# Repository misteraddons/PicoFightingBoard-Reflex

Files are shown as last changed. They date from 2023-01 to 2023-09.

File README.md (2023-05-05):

# Reflex Fighting Board

Open source PCB for arcade sticks using Raspberry Pi Pico's RP2040 microcontroller.

## Introduction

They say imitation is the highest form of flattery. If that's the case then the Brook line of arcade controller boards must be blushing beet red. The Reflex Fighting Board uses the same form factor and layout of the Brook PCBs to maintain compatibility with existing arcade stick cases, wiring harnesses, wire management accessories, etc.

The files for PCB production are in the [Releases](https://github.com/misteraddons/ReflexFightingBoard/tree/main/boards/Reflex_V1) section. The zip file contains the Gerber and drill files, which is all you'll need if you're soldering SMT components yourself. There are also `csv` files for the BOM (Bill of Materials) and component positioning for SMT assembly service.

I will also have premade boards periodically available for purchase at <https://misteraddons.com/collections/parts/products/reflex-encode-fighting-board>.

## Versions, Errata & Changelog

Reflex Encode V1.0:

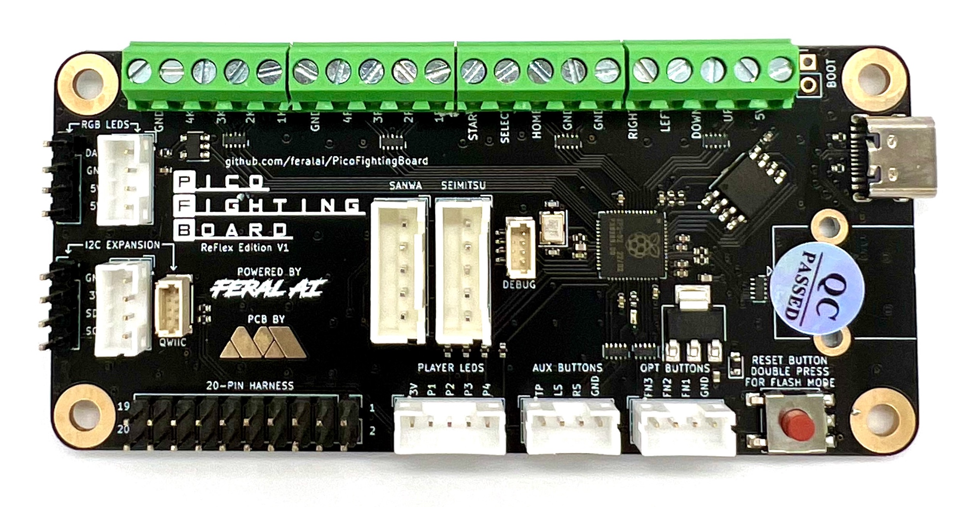
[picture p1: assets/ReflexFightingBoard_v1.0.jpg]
Reflex Fighting Board v1.0


>RGB LED voltage too low - voltage source moved to Vbus (before fuse) instead of +5V (after fuse)

>Pinout = PicoFightingBoard

Reflex Encode V1.1:

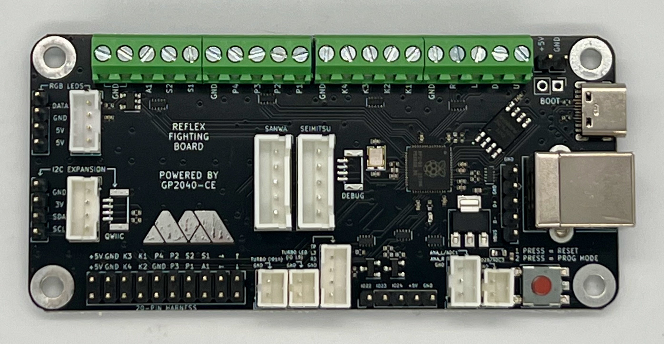
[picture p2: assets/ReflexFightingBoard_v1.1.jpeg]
Reflex Fighting Board v1.1


>Added USB A connector

>Added 5 pin USB header

>Pinout = GP2040

>Added turbo button

>Added turbo LED

>Added spinner header

>Error: Left and Right pins swapped compared to GP2040 pinout

>Error: TP+L3+R3 pinout incompatible with Brook cable

Reflex Encode V1.2:

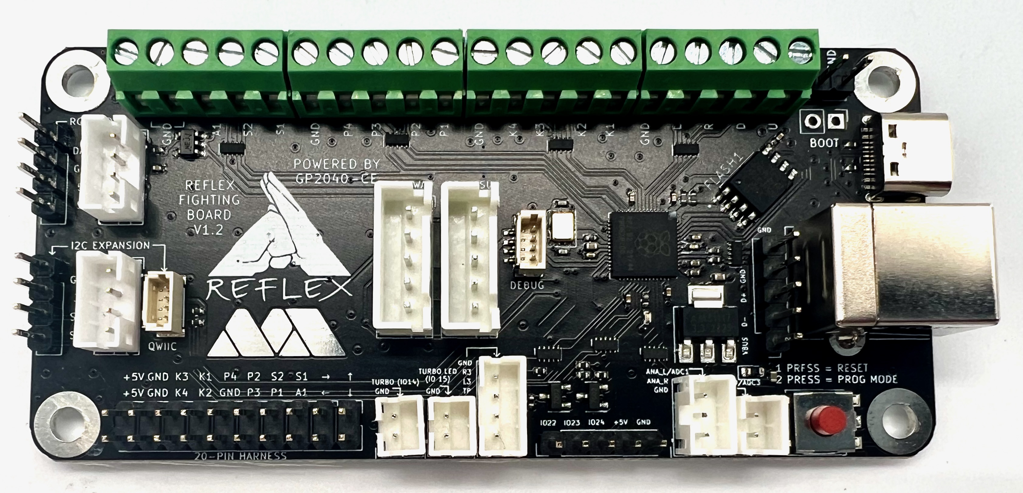
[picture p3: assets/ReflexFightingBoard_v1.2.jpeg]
Reflex Fighting Board v1.2


>Fixed Left / Right pinout

>Fixed TP+L3+R3 pinout

## Firmware

The [GP2040](https://github.com/OpenStickCommunity/GP2040-CE) gamepad firmware for Pi Pico/RP2040 has a pre-configured build for use with the Reflex Fighting Board, providing support for XInput (PC, Android, Raspberry Pi, etc.), DInput (PC/PS3) and Nintendo Switch. [Go to the releases](https://github.com/OpenStickCommunity/GP2040-CE/releases) and download the `GP2040-CE_X.X.X_PicoFightingBoard.uf2`. To flash:

1. Unplug your Reflex Fighting Board.
1. Hold the BOOTSEL button on the Pico and plug into your computer. A new removable drive named `RPI-RP2` should appear in your file explorer.
1. Drag and drop the `GP2040-CE_X.X.X_PicoFightingBoard.uf2` file into the removable drive. This will flash the board.
1. The board should now be running the GP2040 firmware and should appear as a controller on your computer.

## Modification

If you want to modify the PCB layout you'll need the free [KiCad software](https://www.kicad.org/download/) installed. KiCad 6.x/7.x was used for these instructions.

## Support

If you would like to discuss and issues or features with the Reflex Fighting Board, please join the [OpenStick GP2040-CE Discord server](https://discord.gg/k2pxhke7q8) or the [MiSTer Addons Discord server](https://discord.gg/PtUFHtzuYD).

## Contributions

Want to help improve the Reflex Fighting Board? There are a bunch of ways to contribute!

### Pull Requests

Pull requests are welcome and encouraged for enhancements, fixes and documentation updates.

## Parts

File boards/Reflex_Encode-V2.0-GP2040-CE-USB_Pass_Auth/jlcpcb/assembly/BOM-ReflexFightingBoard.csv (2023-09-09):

Comment | Designator | Footprint | LCSC
SN74LV1T34DBV | U2 | SOT-23-5 | C100024
1K | R1,R14,R16 | R_0402_1005Metric | C11702
Conn_01x05 | J22,J24 | PinHeader_1x05_P2.54mm_Vertical | C124379
LED 0402 YELLOW | D2 | LED_0402_1005Metric | C130719
Conn_01x04_Male | J1,J12 | JST_PH_B4B-PH-K_1x04_P2.00mm_Vertical | C131334
SCHOTTKY DIODE | D1 | D_0603_1608Metric | C143772
Conn_01x04_Male | J13,J9 | BOOM_SH_C145961_1x04_P1.00mm_Vertical | C145961
100n | C1,C11,C13,C14,C15,C16,C5,C8,C9 | C_0402_1005Metric | C1525
10u | C17,C6,C7 | C_0402_1005Metric | C15525
27p | C3,C4 | C_0402_1005Metric | C1557
USB_C_Receptacle | J15 | USB_Type_C_C167321 | C165948
RP2040 | U4 | RP2040-QFN-56 | C2040
27 | R18,R19 | R_0402_1005Metric | C25100
330R | R5 | R_0402_1005Metric | C25104
470R | R20 | R_0402_1005Metric | C25117
10K | R15,R2,R3,R4,R8 | R_0402_1005Metric | C25744
4K7 | R6,R7 | R_0402_1005Metric | C25900
5K1 | R21,R22 | R_0402_1005Metric | C25905
SANWA | J17,J18 | JST_XH_B5B-XH-AM_1x05_P2.50mm_Vertical | C2908603
Conn_01x03 | J11 | JST_PH_B3B-PH-K_1x03_P2.00mm_Vertical | C2908624
Conn_01x04_Male | J10,J19 | PinHeader_1x04_P2.54mm_Vertical | C2935910
TVS_RCLAMP0524P-N | U1,U10,U11,U5,U6,U7,U8,U9 | UDFN-10_1.35x2.6mm_P0.5mm | C316044
ST01x05 | J5,J6,J7,J8 | TerminalBlock_MetzConnect_Type059_RT06305HBWC_1x05_P3.50mm_Horizontal | C3646874
USB_B | J16 | USB_B_Lumberg_2411_02_Horizontal | C388656
Conn_01x02 | J20 | PinHeader_1x02_P2.54mm_Vertical | C492401
Conn_02x10_Odd_Even | J2 | PinHeader_2x10_P2.54mm_Vertical | C492427
SW_Push | SW1 | SW_SPST_6x6_C499305_C499302 | C499305
1u | C10,C12 | C_0402_1005Metric | C52923
AMS1117-3.3 | U3 | SOT-223-3_TabPin2 | C6186
Conn_01x02 | J26,J3,J4 | JST_PH_B2B-PH-K_1x02_P2.00mm_Vertical | C722767
Brook 4P Header | J21 | JST_PH_B4B-PH-K_1x04_P2.00mm_Vertical | C722775
W25Q16 | FLASH1 | SOIC127P790X216-8N | C82317
BSS138 | Q1,Q2 | SOT-23 | C8545
Crystal_GND24_Small | Y1 | Crystal_SMD_SeikoEpson_TSX3225-4Pin_3.2x2.5mm | C9002
Conn_01x02 | J14 | PinHeader_1x02_P2.54mm_Vertical

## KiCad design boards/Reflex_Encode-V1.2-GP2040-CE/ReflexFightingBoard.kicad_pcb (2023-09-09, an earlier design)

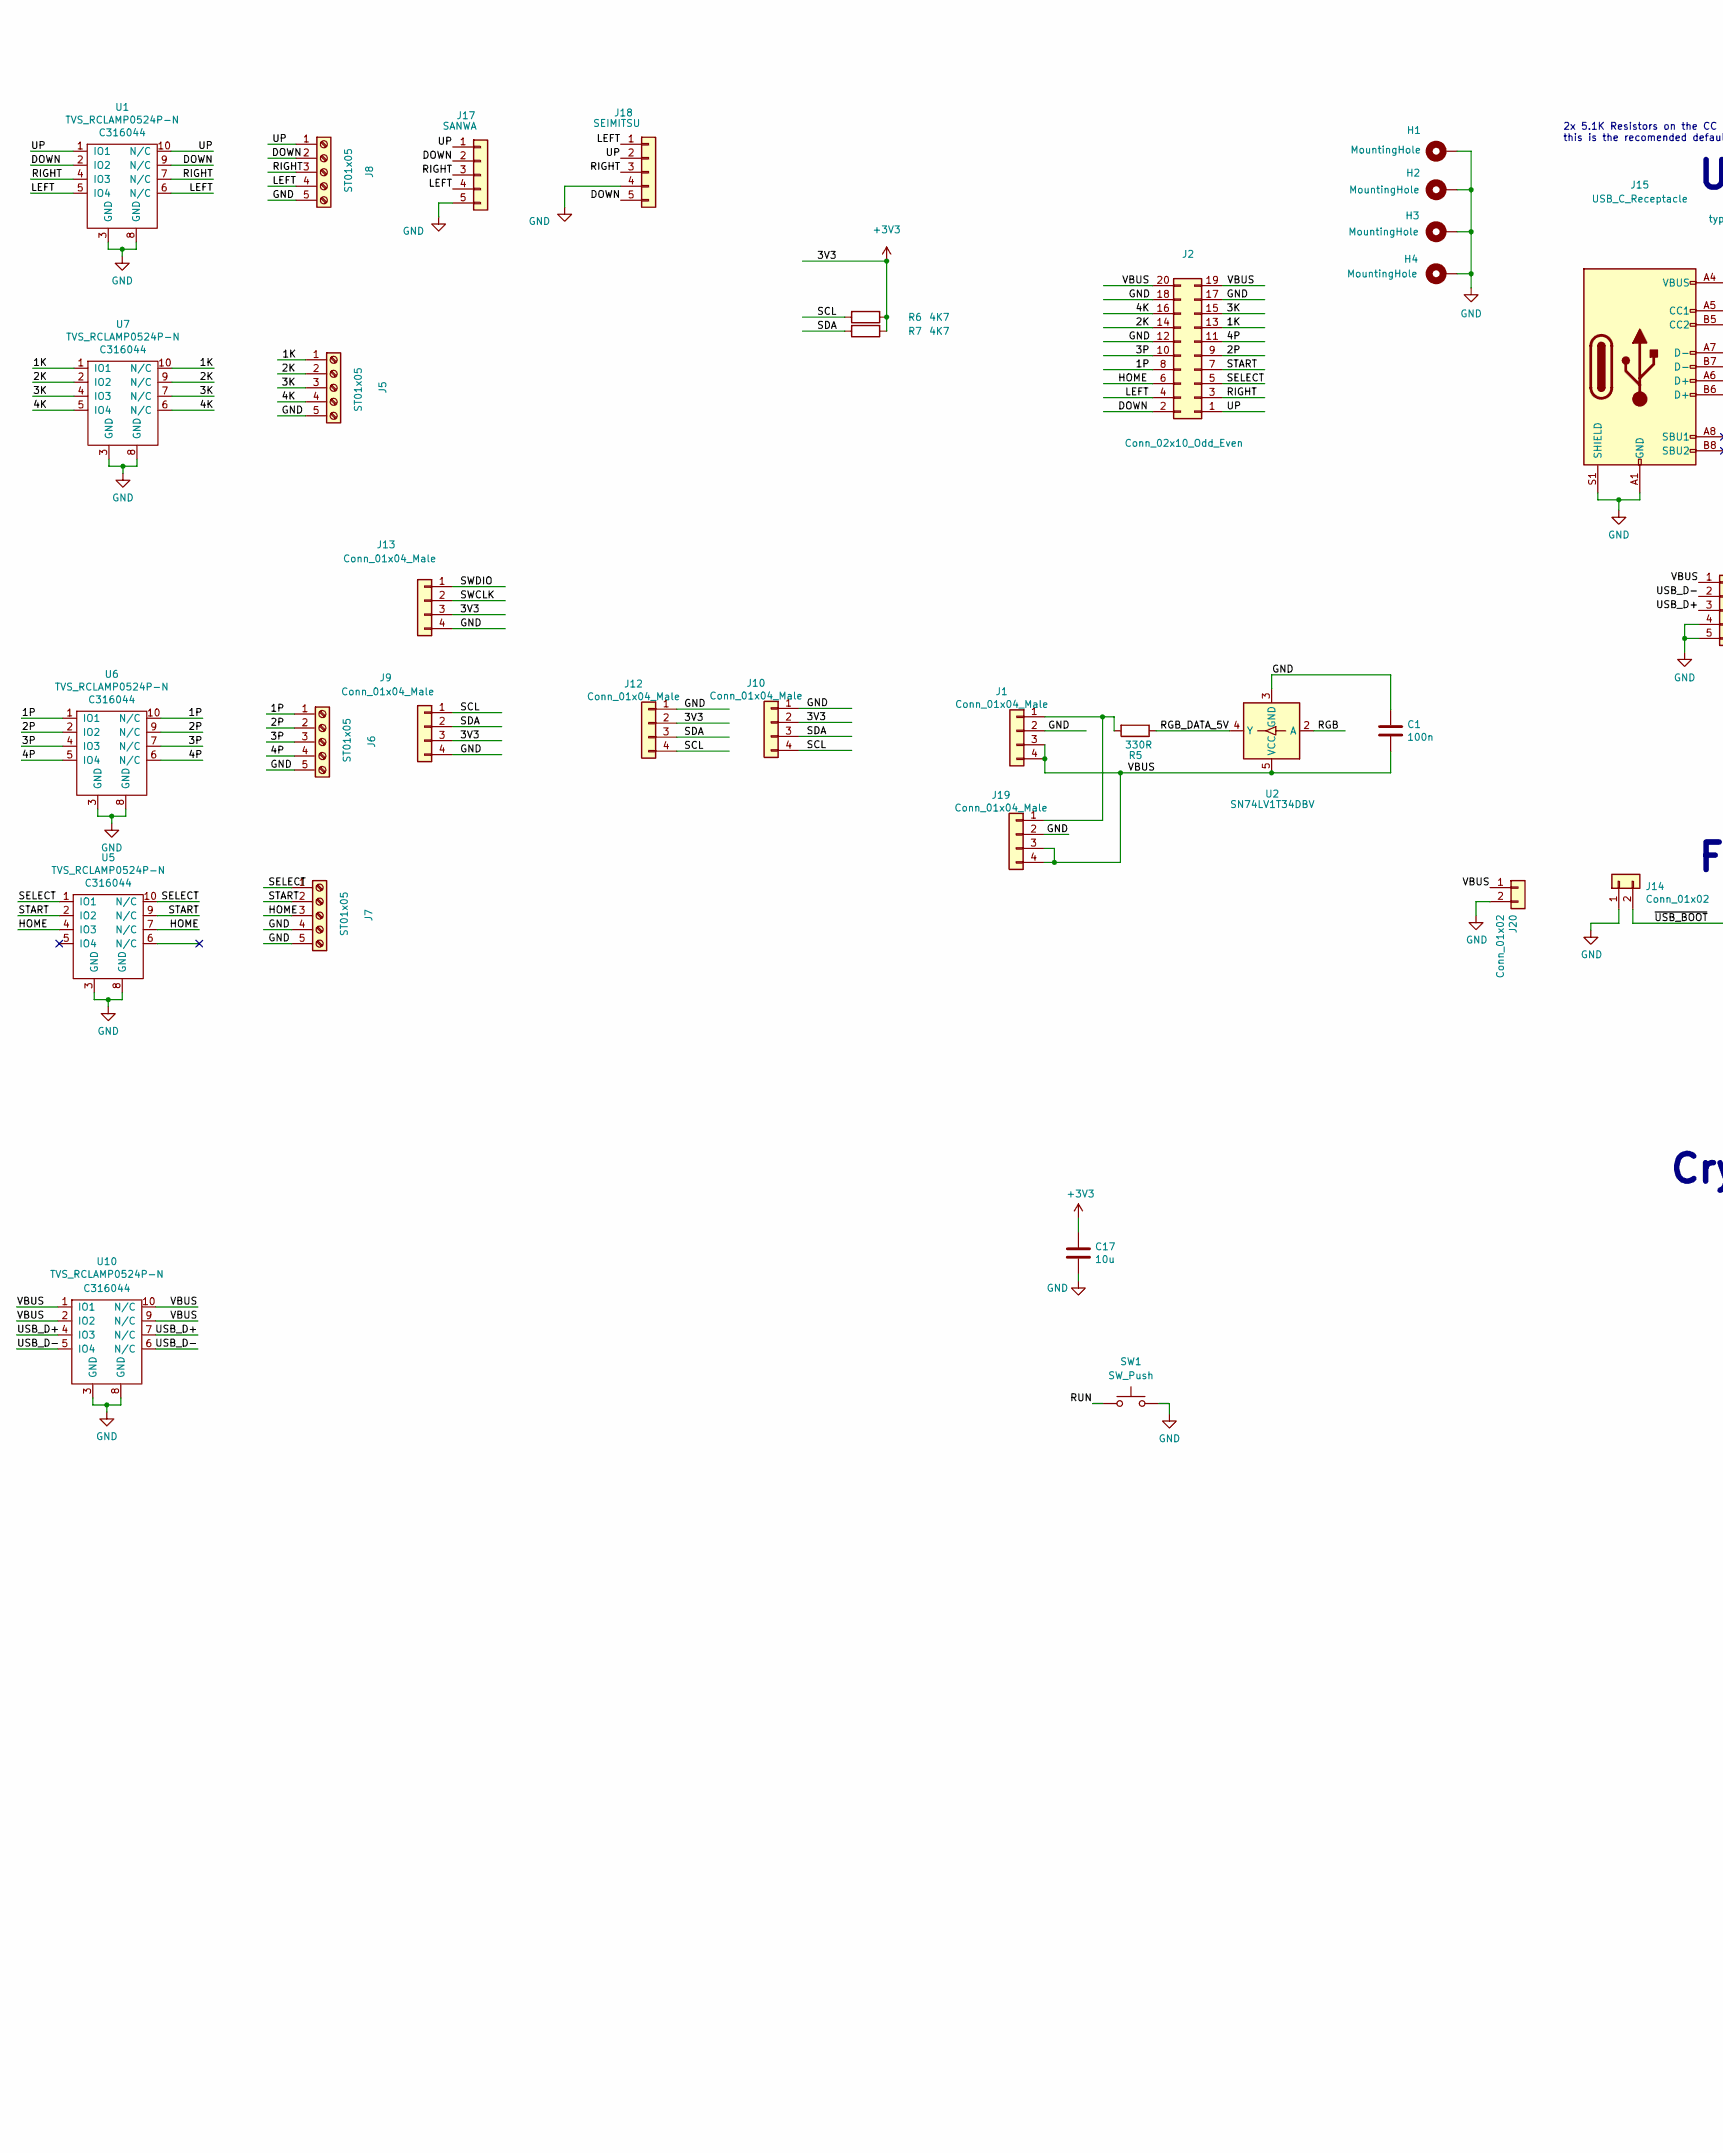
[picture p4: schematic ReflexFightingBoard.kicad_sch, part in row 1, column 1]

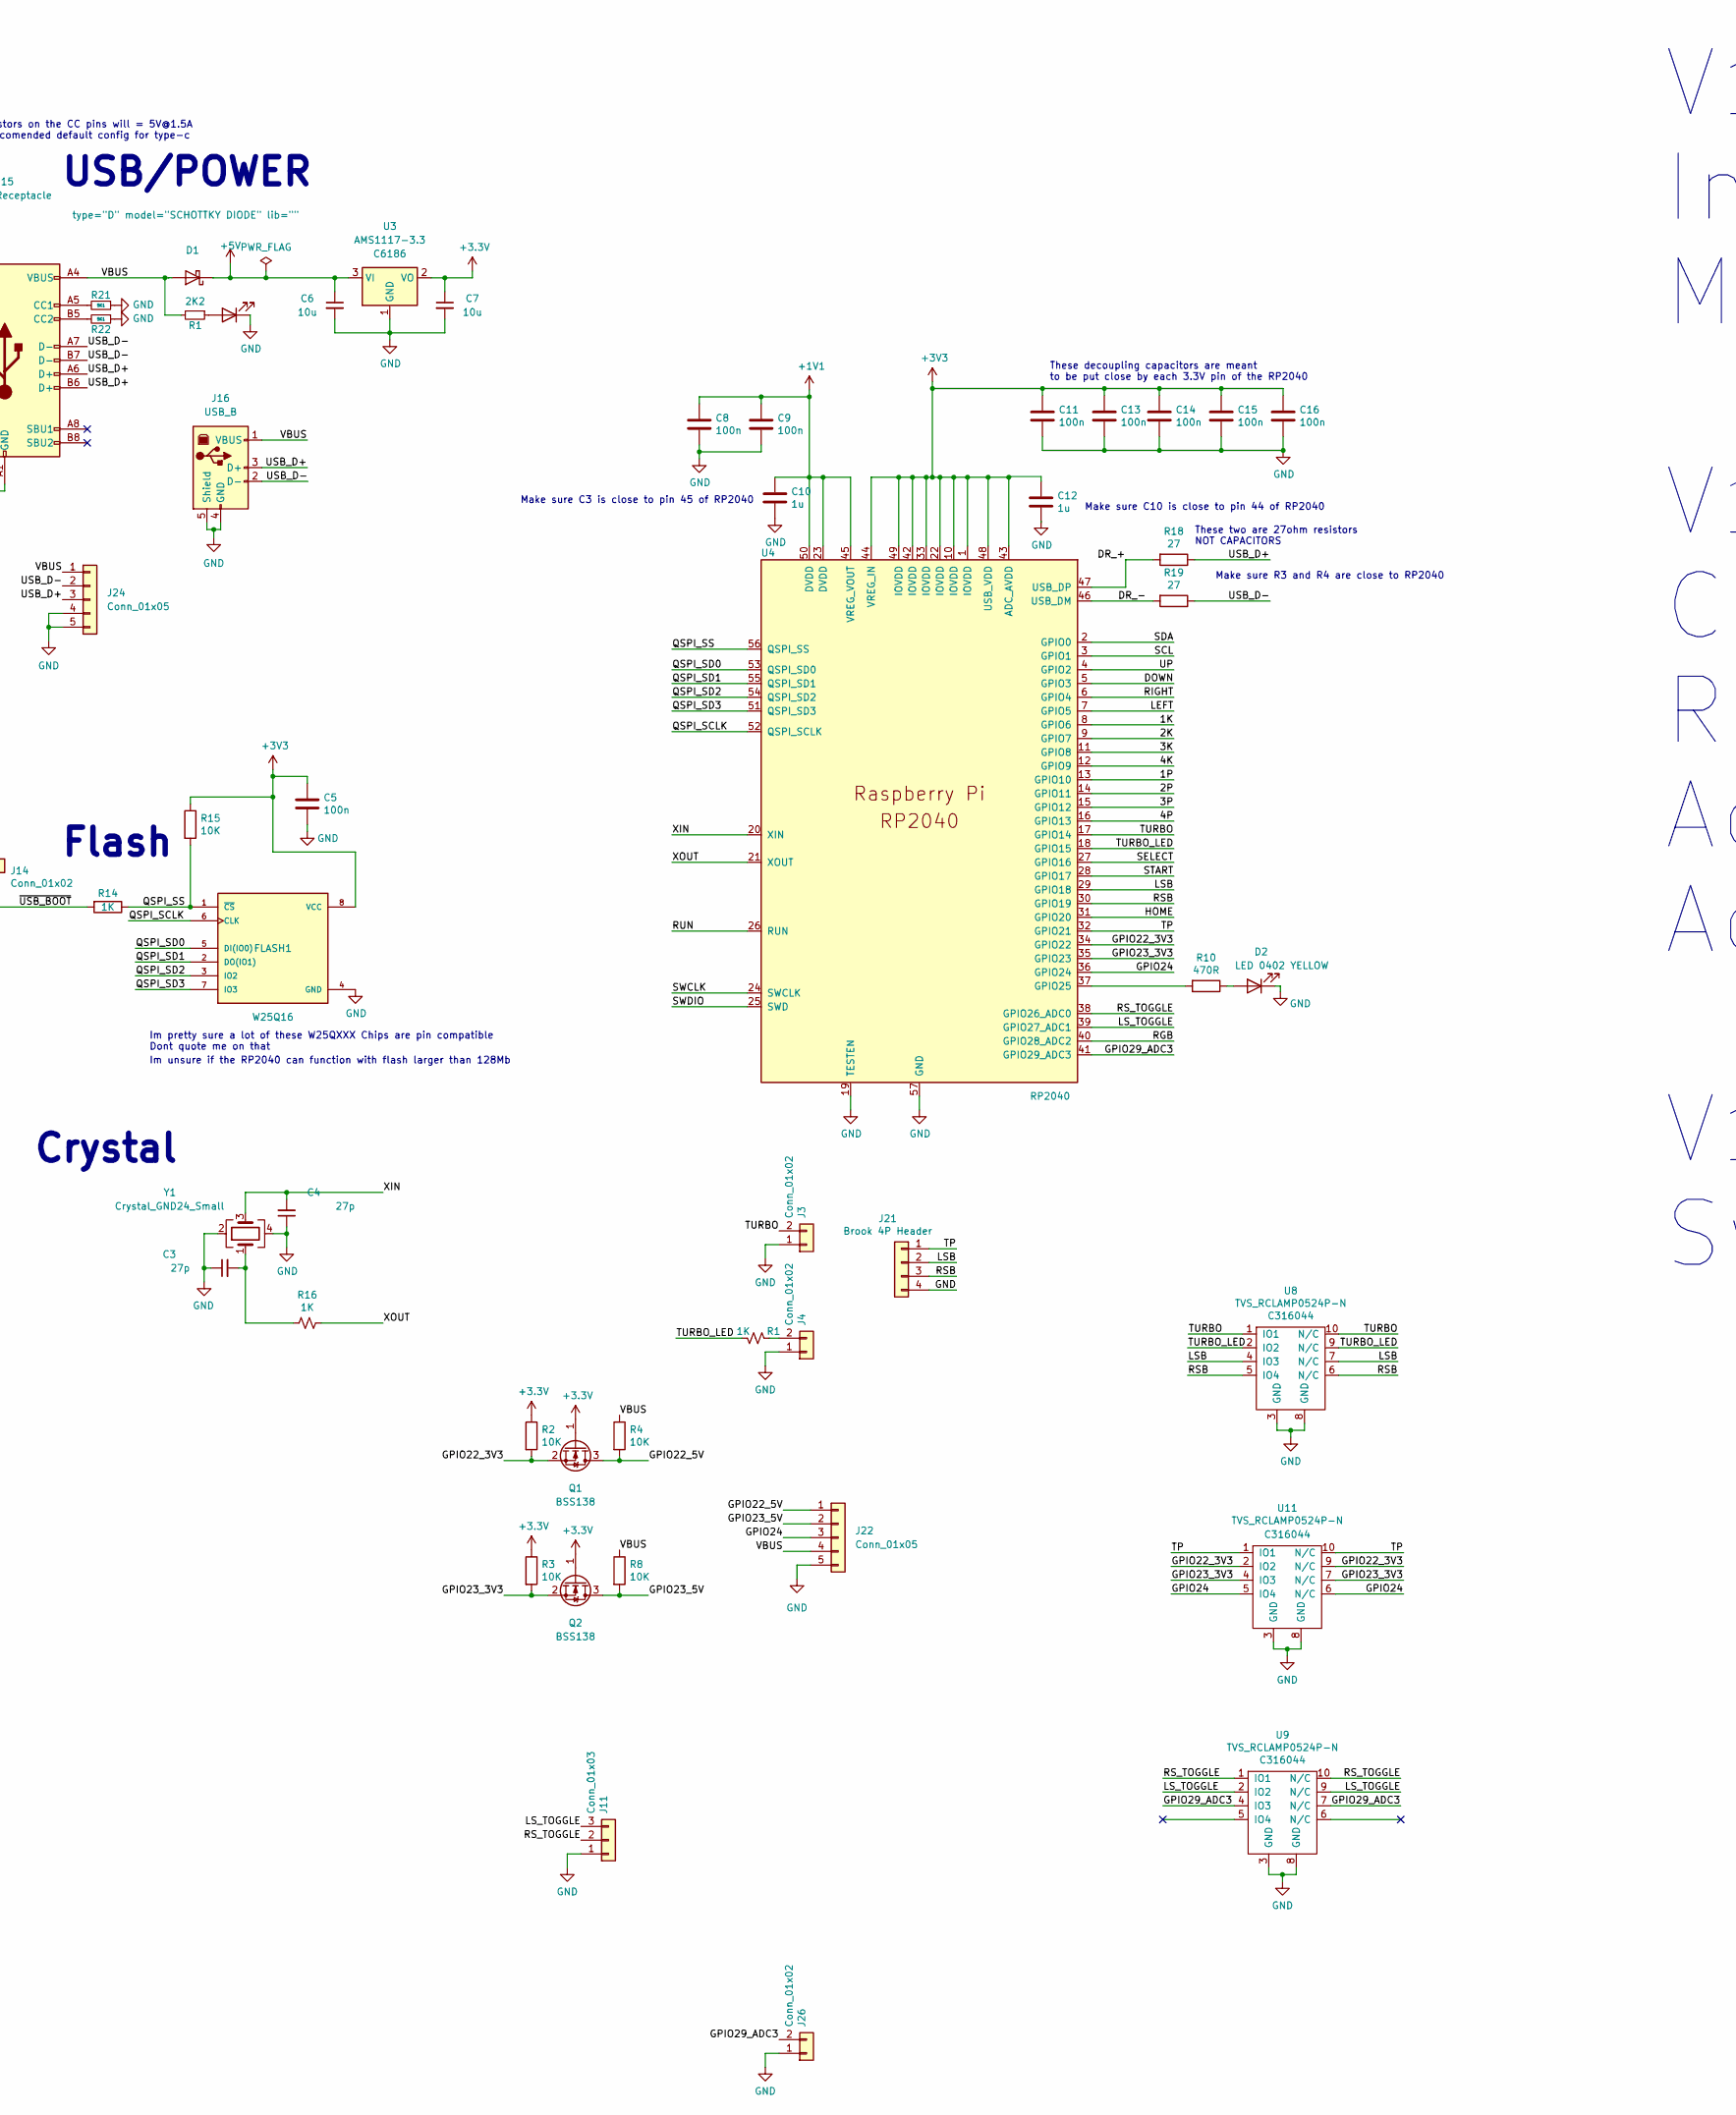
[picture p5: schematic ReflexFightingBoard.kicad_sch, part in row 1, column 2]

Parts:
C1, C5, C8, C9, C11, C13, C14, C15, C16: 100n; C_0402_1005Metric; LCSC Part C1525
C3, C4: 27p; C_0402_1005Metric; LCSC Part C1557
C6, C7, C17: 10u; C_0402_1005Metric; LCSC Part C15525
C10, C12: 1u; C_0402_1005Metric; LCSC Part C52923
D1: type="D" model="SCHOTTKY DIODE" lib=""; D_0603_1608Metric; LCSC Part C143772
D2: LED; LED_0603_1608Metric; LCSC Part C5137313
FLASH1: W25Q16; SOIC127P790X216-8N; LCSC Part C82317
H1, H2, H3, H4: MountingHole; MountingHole_3.5mm_Pad
J1, J12: Conn_01x04_Male; JST_PH_B4B-PH-K_1x04_P2.00mm_Vertical; LCSC Part C131334
J2: Conn_02x10_Odd_Even; PinHeader_2x10_P2.54mm_Vertical; LCSC Part C492427
J3, J4, J26: Conn_01x02; JST_PH_B2B-PH-K_1x02_P2.00mm_Vertical; LCSC Part C722767
J5, J6, J7, J8: ST01x05; TerminalBlock_MetzConnect_Type059_RT06305HBWC_1x05_P3.50mm_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; LCSC Part C3646874
J9, J13: Conn_01x04_Male; BOOM_SH_C145961_1x04_P1.00mm_Vertical; LCSC Part C145961
J10, J19: Conn_01x04_Male; PinHeader_1x04_P2.54mm_Vertical; LCSC Part C2935910
J11: Conn_01x03; JST_PH_B3B-PH-K_1x03_P2.00mm_Vertical; LCSC Part C722771
J14: Conn_01x02; PinHeader_1x02_P2.54mm_Vertical
J15: USB_C_Receptacle; USB_Type_C_C167321; LCSC Part C165948
J16: USB_B; USB_B_Lumberg_2411_02_Horizontal; LCSC Part C388656
J17: SANWA; JST_XH_B5B-XH-AM_1x05_P2.50mm_Vertical; LCSC Part C2908603
J18: SEIMITSU; JST_XH_B5B-XH-AM_1x05_P2.50mm_Vertical; LCSC Part C2908603
J20: Conn_01x02; PinHeader_1x02_P2.54mm_Vertical; LCSC Part C492401
J21: Brook 4P Header; JST_PH_B4B-PH-K_1x04_P2.00mm_Vertical; LCSC Part C722775
J22, J24: Conn_01x05; PinHeader_1x05_P2.54mm_Vertical; LCSC Part C124379
Q1, Q2: BSS138; SOT-23; LCSC Part C8545
R1: 2K2; R_0402_1005Metric; LCSC Part C25879
R2, R3, R4, R8, R15: 10K; R_0402_1005Metric; LCSC Part C25744
R5: 330R; R_0402_1005Metric; LCSC Part C25104
R6, R7: 4K7; R_0402_1005Metric; LCSC Part C25900
R10: 470R; R_0402_1005Metric; LCSC Part C25117
R14: 1K; C_0402_1005Metric; LCSC Part C11702
R16: 1K; R_0402_1005Metric; LCSC Part C11702
R18, R19: 27; R_0402_1005Metric; LCSC Part C25100
R21, R22: 5K1; R_0402_1005Metric; LCSC Part C25905
SW1: SW_Push; SW_SPST_6x6_C499305_C499302; LCSC Part C499305
U1, U5, U6, U7, U8, U9, U10, U11: TVS_RCLAMP0524P-N; UDFN-10_1.35x2.6mm_P0.5mm; LCSC Part C316044
U2: SN74LV1T34DBV; SOT-23-5; LCSC Part C100024
U3: AMS1117-3.3; SOT-223-3_TabPin2; LCSC Part C6186
U4: RP2040; RP2040-QFN-56; LCSC Part C2040
Y1: Crystal_GND24_Small; Crystal_SMD_SeikoEpson_TSX3225-4Pin_3.2x2.5mm; LCSC Part C9002

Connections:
+1V1: C8.1, C9.1, C10.1, U4.23 (DVDD), U4.45 (VREG_VOUT), U4.50 (DVDD)
+5V: C6.1, D1.1 (K), U3.3 (VI)
/1K: J2.13, J5.1, U4.8 (GPIO6), U7.1 (IO1), U7.10 (N/C)
/1P: J2.8, J6.1, U4.13 (GPIO10), U6.1 (IO1), U6.10 (N/C)
/2K: J2.14, J5.2, U4.9 (GPIO7), U7.2 (IO2), U7.9 (N/C)
/2P: J2.9, J6.2, U4.14 (GPIO11), U6.2 (IO2), U6.9 (N/C)
/3K: J2.15, J5.3, U4.11 (GPIO8), U7.4 (IO3), U7.7 (N/C)
/3P: J2.10, J6.3, U4.15 (GPIO12), U6.4 (IO3), U6.7 (N/C)
/4K: J2.16, J5.4, U4.12 (GPIO9), U7.5 (IO4), U7.6 (N/C)
/4P: J2.11, J6.4, U4.16 (GPIO13), U6.5 (IO4), U6.6 (N/C)
/DOWN: J2.2, J8.2, J17.2, J18.5, U1.2 (IO2), U1.9 (N/C), U4.5 (GPIO3)
/DR_+: R18.2, U4.47 (USB_DP)
/DR_-: R19.2, U4.46 (USB_DM)
/GPIO22_3V3: Q1.2 (S), R2.2, U4.34 (GPIO22), U11.2 (IO2), U11.9 (N/C)
/GPIO22_5V: J22.1, Q1.3 (D), R4.2
/GPIO23_3V3: Q2.2 (S), R3.2, U4.35 (GPIO23), U11.4 (IO3), U11.7 (N/C)
/GPIO23_5V: J22.2, Q2.3 (D), R8.2
/GPIO24: J22.3, U4.36 (GPIO24), U11.5 (IO4), U11.6 (N/C)
/GPIO29_ADC3: J26.2, U4.41 (GPIO29_ADC3), U9.4 (IO3), U9.7 (N/C)
/HOME: J2.6, J7.3, U4.31 (GPIO20), U5.4 (IO3), U5.7 (N/C)
/LEFT: J2.4, J8.4, J17.4, J18.1, U1.5 (IO4), U1.6 (N/C), U4.7 (GPIO5)
/LSB: J21.2, U4.29 (GPIO18), U8.4 (IO3), U8.7 (N/C)
/LS_TOGGLE: J11.3, U4.39 (GPIO27_ADC1), U9.2 (IO2), U9.9 (N/C)
/QSPI_SCLK: FLASH1.6 (CLK), U4.52 (QSPI_SCLK)
/QSPI_SD0: FLASH1.5 (DI(IO0)), U4.53 (QSPI_SD0)
/QSPI_SD1: FLASH1.2 (DO(IO1)), U4.55 (QSPI_SD1)
/QSPI_SD2: FLASH1.3 (IO2), U4.54 (QSPI_SD2)
/QSPI_SD3: FLASH1.7 (IO3), U4.51 (QSPI_SD3)
/QSPI_SS: FLASH1.1 (~CS), R14.1, R15.2, U4.56 (QSPI_SS)
/RGB: U2.2 (A), U4.40 (GPIO28_ADC2)
/RGB_DATA_5V: R5.1, U2.4 (Y)
/RIGHT: J2.3, J8.3, J17.3, J18.3, U1.4 (IO3), U1.7 (N/C), U4.6 (GPIO4)
/RSB: J21.3, U4.30 (GPIO19), U8.5 (IO4), U8.6 (N/C)
/RS_TOGGLE: J11.2, U4.38 (GPIO26_ADC0), U9.1 (IO1), U9.10 (N/C)
/RUN: SW1.1, U4.26 (RUN)
/SCL: J9.1, J10.4, J12.4, R6.2, U4.3 (GPIO1)
/SDA: J9.2, J10.3, J12.3, R7.2, U4.2 (GPIO0)
/SELECT: J2.5, J7.1, U4.27 (GPIO16), U5.1 (IO1), U5.10 (N/C)
/START: J2.7, J7.2, U4.28 (GPIO17), U5.2 (IO2), U5.9 (N/C)
/SWCLK: J13.2, U4.24 (SWCLK)
/SWDIO: J13.1, U4.25 (SWD)
/TP: J21.1, U4.32 (GPIO21), U11.1 (IO1), U11.10 (N/C)
/TURBO: J3.2, U4.17 (GPIO14), U8.1 (IO1), U8.10 (N/C)
/UP: J2.1, J8.1, J17.1, J18.2, U1.1 (IO1), U1.10 (N/C), U4.4 (GPIO2)
/USB_D+: J15.A6 (D+), J15.B6 (D+), J16.3 (D+), J24.3, R18.1, U10.4 (IO3), U10.7 (N/C)
/USB_D-: J15.A7 (D-), J15.B7 (D-), J16.2 (D-), J24.2, R19.1, U10.5 (IO4), U10.6 (N/C)
/XIN: C4.2, U4.20 (XIN), Y1.3
/XOUT: R16.1, U4.21 (XOUT)
/~USB_BOOT: J14.2, R14.2
GND: C1.1, C3.1, C4.1, C5.2, C6.2, C7.2, C8.2, C9.2, C10.2, C11.2, C12.2, C13.2, C14.2, C15.2, C16.2, C17.2, D2.1 (K), FLASH1.4 (GND), H1.1, H2.1, H3.1, H4.1, J1.2, J2.12, J2.17, J2.18, J3.1, J4.1, J5.5, J6.5, J7.4, J7.5, J8.5, J9.4, J10.1, J11.1, J12.1, J13.4, J14.1, J15.A1 (GND), J15.A12 (GND), J15.B1 (GND), J15.B12 (GND), J15.S1 (SHIELD), J16.4 (GND), J16.5 (Shield), J17.5, J18.4, J19.2, J20.2, J21.4, J22.5, J24.4, J24.5, J26.1, R21.1, R22.1, SW1.2, U1.3 (GND), U1.8 (GND), U2.3 (GND), U3.1 (GND), U4.19 (TESTEN), U4.57 (GND), U5.3 (GND), U5.8 (GND), U6.3 (GND), U6.8 (GND), U7.3 (GND), U7.8 (GND), U8.3 (GND), U8.8 (GND), U9.3 (GND), U9.8 (GND), U10.3 (GND), U10.8 (GND), U11.3 (GND), U11.8 (GND), Y1.2, Y1.4; also elsewhere on the board
unnamed: C3.2, R16.2, Y1.1
unnamed: J1.1, J19.1, R5.2
unnamed: J15.A5 (CC1), R21.2
unnamed: J15.B5 (CC2), R22.2
unnamed: R10.2, U4.37 (GPIO25)

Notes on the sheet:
Im pretty sure a lot of these W25QXXX Chips are pin compatible Dont quote me on that
Make sure C3 is close to pin 45 of RP2040
Make sure R3 and R4 are close to RP2040
These decoupling capacitors are meant to be put close by each 3.3V pin of the RP2040
These two are 27ohm resistors NOT CAPACITORS
Make sure C10 is close to pin 44 of RP2040
Flash
V1.0 Initial version Messed up USB B pinout V1.1 Changed pinout from Pico Fighting Board to gp2040-ce Removed player leds Added turbo button Added spinner inputs V1.2 Swapped Left and Right
2x 5.1K Resistors on the CC pins will = 5V@1.5A this is the recomended default config for type-c
Im unsure if the RP2040 can function with flash larger than 128Mb
USB/POWER
Crystal

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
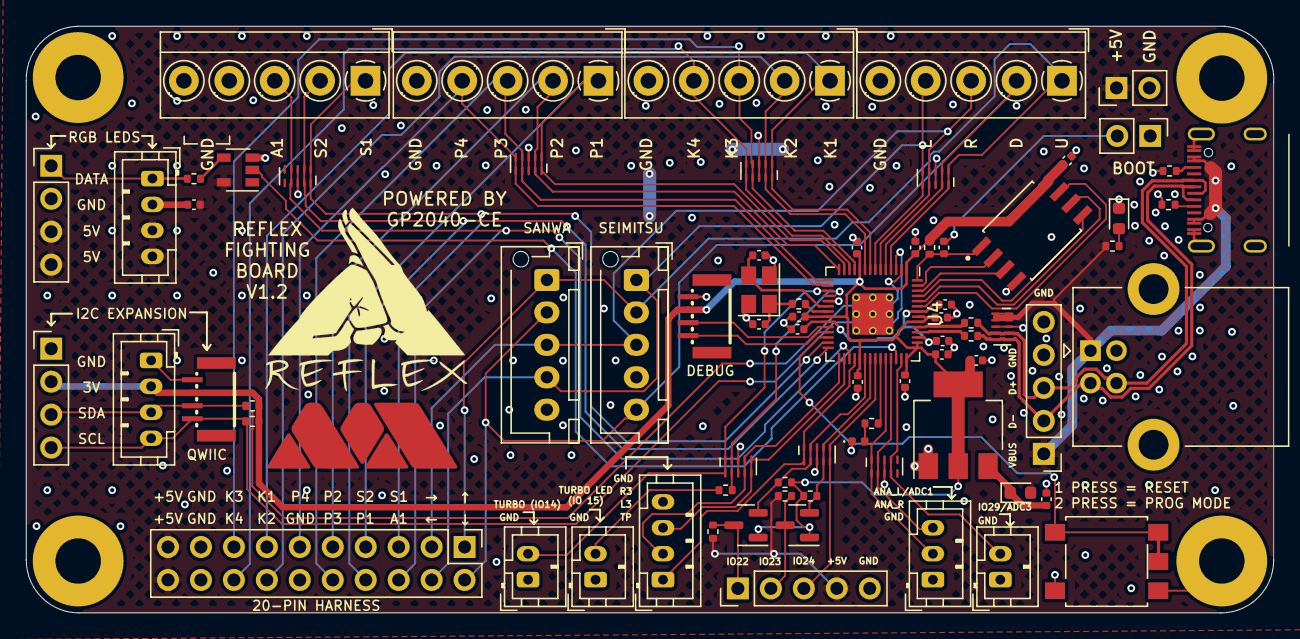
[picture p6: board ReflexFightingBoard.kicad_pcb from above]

Board: 4 copper layers, 96.1 x 45.2 mm, 83 parts (1 on the bottom side), 61 nets.

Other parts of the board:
D3: LED; LED_0603_1608Metric
R9: 2K2; R_0402_1005Metric
Ref**: Val**; MiSTer_Addons_MA_15mm
Ref**#2: Val**; Reflex_Encode-Silk-15mm
Ref**#3: Val**; Idaho_M

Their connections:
GND: D3.1 (K); also elsewhere on the board
unnamed: D3.2 (A), R9.1

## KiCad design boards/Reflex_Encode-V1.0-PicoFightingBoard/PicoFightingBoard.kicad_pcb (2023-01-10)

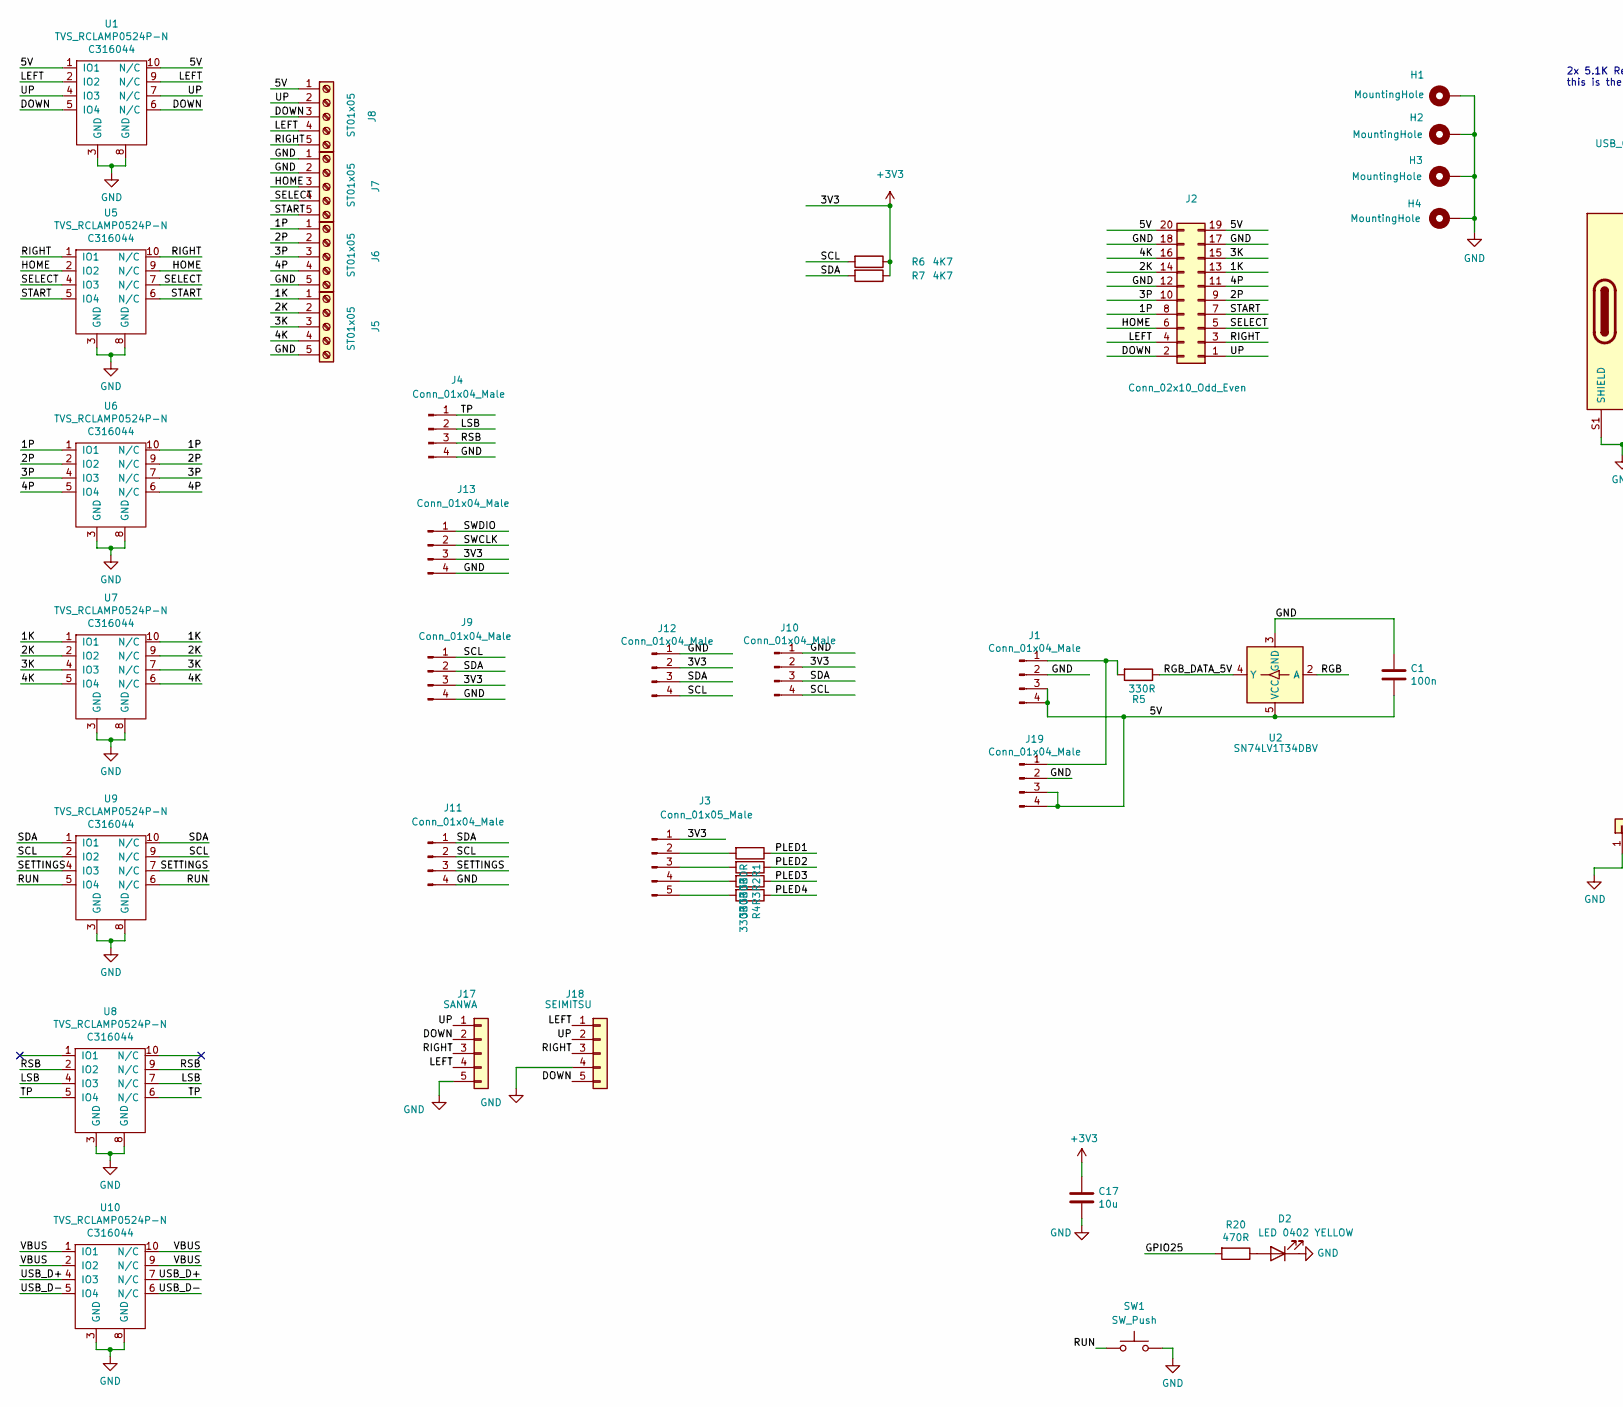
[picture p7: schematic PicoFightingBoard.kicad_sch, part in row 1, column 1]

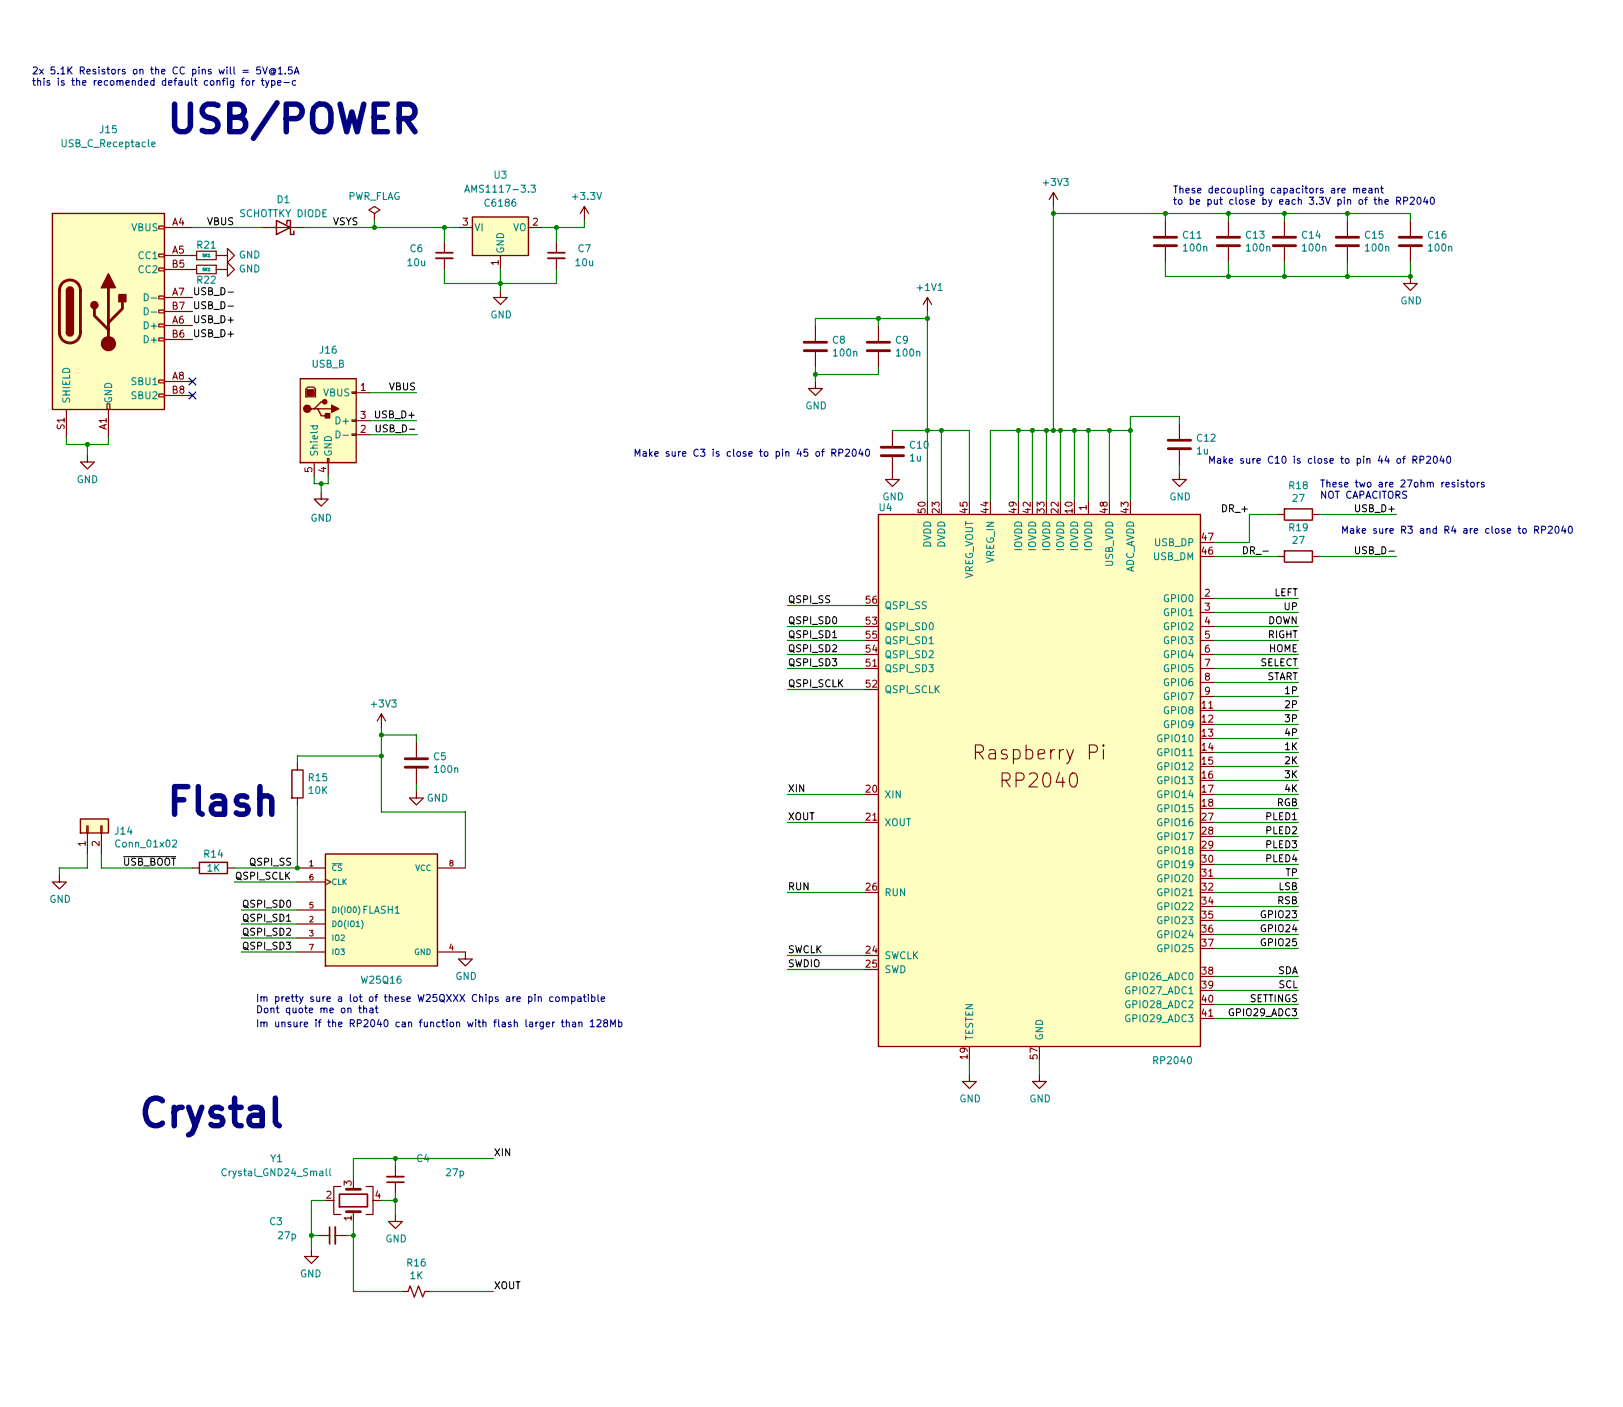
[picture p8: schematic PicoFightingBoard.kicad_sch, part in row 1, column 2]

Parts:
C1, C5, C8, C9, C11, C13, C14, C15, C16: 100n; C_0402_1005Metric; LCSC Part C1525
C3, C4: 27p; C_0402_1005Metric; LCSC Part C1557
C6, C7, C17: 10u; C_0402_1005Metric; LCSC Part C15525
C10, C12: 1u; C_0402_1005Metric; LCSC Part C52923
D1: SCHOTTKY DIODE; D_0603_1608Metric; LCSC Part C143772
D2: LED 0402 YELLOW; LED_0402_1005Metric; LCSC Part C130719
FLASH1: W25Q16; SOIC127P790X216-8N; LCSC Part C82317
H1, H2, H3, H4: MountingHole; MountingHole_3.5mm_Pad
J1, J4, J11, J12: Conn_01x04_Male; JST_PH_B4B-PH-K_1x04_P2.00mm_Vertical; LCSC Part C131334
J2: Conn_02x10_Odd_Even; PinHeader_2x10_P2.54mm_Vertical; LCSC Part C492427
J3: Conn_01x05_Male; JST_PH_B5B-PH-K_1x05_P2.00mm_Vertical; LCSC Part C157993
J5, J6, J7, J8: ST01x05; TerminalBlock_MetzConnect_Type059_RT06305HBWC_1x05_P3.50mm_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; LCSC Part C3646874
J9, J13: Conn_01x04_Male; BOOM_SH_C145961_1x04_P1.00mm_Vertical; LCSC Part C145961
J10, J19: Conn_01x04_Male; PinHeader_1x04_P2.54mm_Vertical; LCSC Part C2935910
J14: Conn_01x02; PinHeader_1x02_P2.54mm_Vertical
J15: USB_C_Receptacle; USB_Type_C_C167321; LCSC Part C167321
J16: USB_B; USB_B_Lumberg_2411_02_Horizontal; LCSC Part C388656
J17: SANWA; JST_XH_B5B-XH-AM_1x05_P2.50mm_Vertical; LCSC Part C2908603
J18: SEIMITSU; JST_XH_B5B-XH-AM_1x05_P2.50mm_Vertical; LCSC Part C2908603
R1, R2, R3, R4, R5: 330R; R_0402_1005Metric; LCSC Part C25104
R6, R7: 4K7; R_0402_1005Metric; LCSC Part C25900
R14: 1K; C_0402_1005Metric; LCSC Part C11702
R15: 10K; R_0402_1005Metric; LCSC Part C25744
R16: 1K; R_0402_1005Metric; LCSC Part C11702
R18, R19: 27; R_0402_1005Metric; LCSC Part C25100
R20: 470R; R_0402_1005Metric; LCSC Part C25117
R21, R22: 5K1; R_0402_1005Metric; LCSC Part C25905
SW1: SW_Push; SW_SPST_6x6_C499305_C499302; LCSC Part C499305
U1, U5, U6, U7, U8, U9, U10: TVS_RCLAMP0524P-N; UDFN-10_1.35x2.6mm_P0.5mm; LCSC Part C316044
U2: SN74LV1T34DBV; SOT-23-5; LCSC Part C100024
U3: AMS1117-3.3; SOT-223-3_TabPin2; LCSC Part C6186
U4: RP2040; RP2040-QFN-56; LCSC Part C2040
Y1: Crystal_GND24_Small; Crystal_SMD_SeikoEpson_TSX3225-4Pin_3.2x2.5mm; LCSC Part C9002

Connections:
+1V1: C8.1, C9.1, C10.1, U4.23 (DVDD), U4.45 (VREG_VOUT), U4.50 (DVDD)
/1K: J2.13, J5.1, U4.14 (GPIO11), U7.1 (IO1), U7.10 (N/C)
/1P: J2.8, J6.1, U4.9 (GPIO7), U6.1 (IO1), U6.10 (N/C)
/2K: J2.14, J5.2, U4.15 (GPIO12), U7.2 (IO2), U7.9 (N/C)
/2P: J2.9, J6.2, U4.11 (GPIO8), U6.2 (IO2), U6.9 (N/C)
/3K: J2.15, J5.3, U4.16 (GPIO13), U7.4 (IO3), U7.7 (N/C)
/3P: J2.10, J6.3, U4.12 (GPIO9), U6.4 (IO3), U6.7 (N/C)
/4K: J2.16, J5.4, U4.17 (GPIO14), U7.5 (IO4), U7.6 (N/C)
/4P: J2.11, J6.4, U4.13 (GPIO10), U6.5 (IO4), U6.6 (N/C)
/5V: C1.2, J1.3, J1.4, J2.19, J2.20, J8.1, J19.3, J19.4, U1.1 (IO1), U1.10 (N/C), U2.5 (VCC)
/DOWN: J2.2, J8.3, J17.2, J18.5, U1.5 (IO4), U1.6 (N/C), U4.4 (GPIO2)
/DR_+: R18.2, U4.47 (USB_DP)
/DR_-: R19.2, U4.46 (USB_DM)
/GPIO23: U4.35 (GPIO23)
/GPIO24: U4.36 (GPIO24)
/GPIO25: R20.2, U4.37 (GPIO25)
/GPIO29_ADC3: U4.41 (GPIO29_ADC3)
/HOME: J2.6, J7.3, U4.6 (GPIO4), U5.2 (IO2), U5.9 (N/C)
/LEFT: J2.4, J8.4, J17.4, J18.1, U1.2 (IO2), U1.9 (N/C), U4.2 (GPIO0)
/LSB: J4.2, U4.32 (GPIO21), U8.4 (IO3), U8.7 (N/C)
/PLED1: R1.1, U4.27 (GPIO16)
/PLED2: R2.1, U4.28 (GPIO17)
/PLED3: R3.1, U4.29 (GPIO18)
/PLED4: R4.1, U4.30 (GPIO19)
/QSPI_SCLK: FLASH1.6 (CLK), U4.52 (QSPI_SCLK)
/QSPI_SD0: FLASH1.5 (DI(IO0)), U4.53 (QSPI_SD0)
/QSPI_SD1: FLASH1.2 (DO(IO1)), U4.55 (QSPI_SD1)
/QSPI_SD2: FLASH1.3 (IO2), U4.54 (QSPI_SD2)
/QSPI_SD3: FLASH1.7 (IO3), U4.51 (QSPI_SD3)
/QSPI_SS: FLASH1.1 (~CS), R14.1, R15.2, U4.56 (QSPI_SS)
/RGB: U2.2 (A), U4.18 (GPIO15)
/RGB_DATA_5V: R5.1, U2.4 (Y)
/RIGHT: J2.3, J8.5, J17.3, J18.3, U4.5 (GPIO3), U5.1 (IO1), U5.10 (N/C)
/RSB: J4.3, U4.34 (GPIO22), U8.2 (IO2), U8.9 (N/C)
/RUN: SW1.1, U4.26 (RUN), U9.5 (IO4), U9.6 (N/C)
/SCL: J9.1, J10.4, J11.2, J12.4, R6.2, U4.39 (GPIO27_ADC1), U9.2 (IO2), U9.9 (N/C)
/SDA: J9.2, J10.3, J11.1, J12.3, R7.2, U4.38 (GPIO26_ADC0), U9.1 (IO1), U9.10 (N/C)
/SELECT: J2.5, J7.4, U4.7 (GPIO5), U5.4 (IO3), U5.7 (N/C)
/SETTINGS: J11.3, U4.40 (GPIO28_ADC2), U9.4 (IO3), U9.7 (N/C)
/START: J2.7, J7.5, U4.8 (GPIO6), U5.5 (IO4), U5.6 (N/C)
/SWCLK: J13.2, U4.24 (SWCLK)
/SWDIO: J13.1, U4.25 (SWD)
/TP: J4.1, U4.31 (GPIO20), U8.5 (IO4), U8.6 (N/C)
/UP: J2.1, J8.2, J17.1, J18.2, U1.4 (IO3), U1.7 (N/C), U4.3 (GPIO1)
/USB_D+: J15.A6 (D+), J15.B6 (D+), J16.3 (D+), R18.1, U10.4 (IO3), U10.7 (N/C)
/USB_D-: J15.A7 (D-), J15.B7 (D-), J16.2 (D-), R19.1, U10.5 (IO4), U10.6 (N/C)
/VBUS: D1.2 (A), J15.A4 (VBUS), J15.A9 (VBUS), J15.B4 (VBUS), J15.B9 (VBUS), J16.1 (VBUS), U10.1 (IO1), U10.2 (IO2), U10.9 (N/C), U10.10 (N/C)
/VSYS: C6.1, D1.1 (K), U3.3 (VI)
/XIN: C4.2, U4.20 (XIN), Y1.3
/XOUT: R16.1, U4.21 (XOUT)
/~USB_BOOT: J14.2, R14.2
GND: C1.1, C3.1, C4.1, C5.2, C6.2, C7.2, C8.2, C9.2, C10.2, C11.2, C12.2, C13.2, C14.2, C15.2, C16.2, C17.2, D2.1 (K), FLASH1.4 (GND), H1.1, H2.1, H3.1, H4.1, J1.2, J2.12, J2.17, J2.18, J4.4, J5.5, J6.5, J7.1, J7.2, J9.4, J10.1, J11.4, J12.1, J13.4, J14.1, J15.A1 (GND), J15.A12 (GND), J15.B1 (GND), J15.B12 (GND), J15.S1 (SHIELD), J16.4 (GND), J16.5 (Shield), J17.5, J18.4, J19.2, R21.1, R22.1, SW1.2, U1.3 (GND), U1.8 (GND), U2.3 (GND), U3.1 (GND), U4.19 (TESTEN), U4.57 (GND), U5.3 (GND), U5.8 (GND), U6.3 (GND), U6.8 (GND), U7.3 (GND), U7.8 (GND), U8.3 (GND), U8.8 (GND), U9.3 (GND), U9.8 (GND), U10.3 (GND), U10.8 (GND), Y1.2, Y1.4
unnamed: C3.2, R16.2, Y1.1
unnamed: D2.2 (A), R20.1
unnamed: J1.1, J19.1, R5.2
unnamed: J3.2, R1.2
unnamed: J3.3, R2.2
unnamed: J3.4, R3.2
unnamed: J3.5, R4.2
unnamed: J15.A5 (CC1), R21.2
unnamed: J15.B5 (CC2), R22.2

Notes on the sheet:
Im pretty sure a lot of these W25QXXX Chips are pin compatible Dont quote me on that
Make sure C3 is close to pin 45 of RP2040
Make sure R3 and R4 are close to RP2040
These decoupling capacitors are meant to be put close by each 3.3V pin of the RP2040
These two are 27ohm resistors NOT CAPACITORS
Make sure C10 is close to pin 44 of RP2040
Flash
2x 5.1K Resistors on the CC pins will = 5V@1.5A this is the recomended default config for type-c
Im unsure if the RP2040 can function with flash larger than 128Mb
USB/POWER
Crystal

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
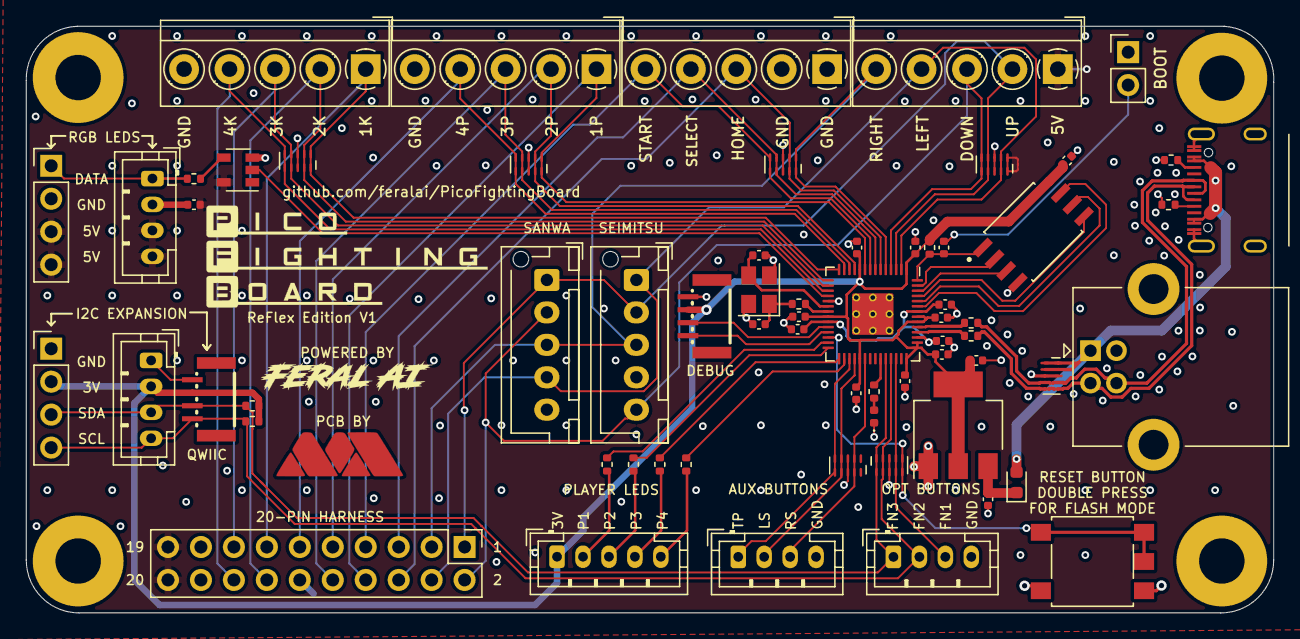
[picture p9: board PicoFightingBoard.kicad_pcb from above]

Board: 4 copper layers, 96.1 x 45.2 mm, 71 parts (1 on the bottom side), 59 nets.

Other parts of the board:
Ref**: Val**; MiSTer_Addons_MA_10mm
Ref**#2: Val**; Idaho_M

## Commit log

2022-11-21 Reflex Edition
    Placed RP2040 on main PCB
    Added TVS protection diodes
    Fixed mounting hole alignment
    Added 2.54mm pin headers for OLED and RGB LEDs
    Added Sanwa and Seimitsu headers for direct joystick connection
    Added USB-C connector
    Added potato logo
    [PicoFightingBoard-Reflex-V1_BOM.csv, PicoFightingBoard.kicad_pcb, PicoFightingBoard.kicad_sch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]
2023-01-10 Create Reflex Fighting Board V1.0.jpg
2023-01-11 Rename Pico Fighting Board to Reflex Fighting Board
    Updated silkscreen, and Github link
    [BOM-ReflexFightingBoard.csv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]
2023-02-21 V1.1 Upload
    [BOM-ReflexFightingBoard.csv, PicoFightingBoard.csv, PicoFightingBoard.kicad_pcb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]
2023-02-21 Remove extra files
    [PicoFightingBoard.kicad_sch]
2023-02-21 Rename Board Revisions
    [BOM-ReflexFightingBoard.csv, PicoFightingBoard.kicad_pcb, PicoFightingBoard.kicad_sch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]
2023-02-21 Upload firmware and rename
    [BOM-ReflexFightingBoard.csv, PicoFightingBoard.kicad_pcb, PicoFightingBoard.kicad_sch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]
2023-09-09 Update revisions
    [BOM-ReflexFightingBoard.csv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]
2023-10-15 Reflex Encode V2 Source
    [BOM-ReflexFightingBoard.csv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]
